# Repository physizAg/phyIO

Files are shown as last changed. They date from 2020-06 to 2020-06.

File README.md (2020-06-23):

# What is PhyIO

PhyIO is an IoT development board with ARM cortex-M4 MCU and CC3100 WiFi chipset. It is designed for tinkerers who need high processing and good wireless connectivity for their IoT projects.

Multiple onboard interfaces like I2C, UART, SPI, and RS485 make it easy to experiment with various sensors and actuators. With its extensive features and rugged design, there are endless possibilities.

# Features

1) Onboard Cortex-M4 based STM32 MCU
2) The PhyIO's wireless chip supports 802.11ac/a/b/g/n WiFI
3) Regulates 12V input to 5V and 3.3V
4) Supports transistor-based switching for driving loads
5) Supports I2C, SPI, UART, and RS485 interface
6) Onboard power indicator LED
7) Flexibility to select specific voltage levels amongst multiple voltage levels for interfaces

## Specs

<li>12V input supply</li>
<li>1 MB Flash memory</li>
<li>256Kb RAM</li>
<li>8 I2C ports</li>
<li>4 SPI ports</li>
<li>1 UART port</li>
<li>RS485 port</li>
<li>10 GPIO ports</li>
<li>4 12-bit ADC channels</li>

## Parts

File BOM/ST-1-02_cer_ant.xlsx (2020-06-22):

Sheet: Лист1
Schematic Reference | Qty | Manufacturer | MPN | Description | SKU
 |  |  |  |  | Digi-Key
ANT1 | 1 | Taiyo Yuden | AH316M245001-T | SMD antenna | 587-2200-1-ND
C1, C2 | 2 | Yageo | CC1206ZKY5V8BB106 | 10uF 25V 1206 smd capacitor | 311-3463-1-ND
C3, C4 | 2 | Yageo | CC0603KRX7R9BB103 | 10nF 50V 0603 X7R, smd capacitor | 311-1085-1-ND
C5, C6 | 2 | Murata | GRM31CR60J107ME39K | 100uF 6.3V 1206 smd capacitor | 490-7217-1-ND
C7, C13, C14, C15, C16, C17, C19, C23 | 8 | Yageo | CC0603KRX7R7BB104 | 0.1uF 16V 0603 smd capacitor | 311-1088-1-ND
C8, C10 | 2 | Yageo | CC0603JRNPO9BN120 | 12pF 0603 smd capacitor | 311-1059-1-ND
C9, C11 | 2 | Yageo | CC0603JRNPO9BN180 | 18pF 0603 smd capacitor | 311-1061-1-ND
C12 | 1 | Yageo | CC0603KRX5R7BB225 | 2.2uF 16V 0603 smd capacitor | 311-1784-1-ND
C20 | 1 | Yageo | CC0402BRNPO9BN1R0 | 1 pF, 0402 ceramic capacitor | 311-3613-1-ND
C21 | 1 | KEMET | T491B107K006AT | B case 100uF, 6V | 399-8301-1-ND
C24, C25 | 2 | Vishay | 293D107X9010D2TE3 | D case 100uF 10V | 718-1056-1-ND
D1, D2 | 2 | STMicroelectronics | STPS140Z | 1.5A Bridge Rectifier | 497-7546-1-ND
D3, D4, D5 | 3 | WГјrth Elektronik | 150060VS75000 | SMD LED, Green | 732-4980-1-ND
D6, D7 | 2 | ON Semiconductor | RB521S30T1G | shottky diode SOD-523 | RB521S30T1GOSCT-ND
L1, L2 | 2 | Bourns | SRN8040-330M | SMD Inductor 33uH | SRN8040-330MCT-ND
L3, L5, L6 | 3 | Murata | BLM18PG121SN1D | Ferrite: bead 120О© 2A 0603 50mО© | 490-1037-1-ND
L4 | 1 | Taiyo Yuden | HK10053N6S-T | 3.6 nH, 0402 inductor | 587-1508-1-ND
Q1, Q2, Q3, Q4, Q5, Q6, Q7, Q8, Q9, Q10 | 10 | Infineon | IRLML2803TRPBF | MOSFET | IRLML2803PBFCT-ND
R1, R2 | 2 | Yageo | RC0603FR-07470KL | 470K 1%, smd resistor | 311-470KHRCT-ND
R3, R5, R16, R19,R20,R25,R26 | 7 | Yageo | RC0603FR-0710KL | 10K, 1%, smd resistor | 311-10.0KHRCT-ND
R4 | 1 | Yageo | RC0603FR-073K24L | 3.24K 1%, smd resistor | 311-3.24KHRCT-ND
R6 | 1 | Yageo | RC0603FR-075K9L | 5.9K 1%, smd resistor | 311-5.90KHRCT-ND
R7 | 1 | Yageo | RC0805FR-07150RL | 150 Ohm 1%, smd resistor | 311-150CRCT-ND
R8, R9 | 2 | Yageo | RC0603FR-07330RL | 330 Ohm 1%, smd resistor | 311-330HRCT-ND
R10, R11, R12, R13, R14 | 5 | Yageo | RC0603FR-071KL | 1K 1%, smd resistor | 311-1.00KHRCT-ND
R15, R17, R18, R21, R22, R23, R24, R27, R28, R29, R30, R33 | 12 | Yageo | RC0603JR-10100KL | 100K, smd resistor | YAG2294CT-ND
R31 | 1 | Yageo | RC0402FR-070RL | 0 Ohm 1%, smd resistor | 311-0.0LRCT-ND
R34 | 1 | Yageo | RC1206JR-07270RL | 270 Ohm, 1206 resistor | 311-270ERCT-ND
R35 | 1 | Yageo | RC1206JR-07180RL | 180 Ohm, 1206 resistor | 311-180ERCT-ND
SW1 | 1 | TE Connectivity | FSMSM | TE smd button switch | 450-1140-ND
U1, U2 | 2 | Texas Instruments | TPS5410DR | Step-down regulator | 296-26982-1-ND
U3 | 1 | STMicroelectronics | ST3485EBDR | MAXIM, RS-422/RS-485 isolated driver | 497-2080-1-ND
U4 | 1 | STMicroelectronics | STM32F412RGT6 | STM32 MCU | 497-16764-ND
U5 | 1 | Texas Instruments | CC3100MODR11MAMOBR | CC3100 MODULE | 296-43589-1-ND
X1, X41 | 2 | WГјrth Elektronik | 691137710002 | 5mm Terminal Block 2pos | 732-10955-ND
X2 | 1 | WГјrth Elektronik | 691137710003 | 5mm Terminal Block 3pos | 732-10956-ND
X3 | 1 | CNC Tech | 3220-10-0300-00 | SWD connector | 1175-1629-ND
X4 | 1 | WГјrth Elektronik | 61300211121 | Male 2 Pos Header Connector 0.1" | 732-5315-ND
X5, X19, X40 | 3 | WГјrth Elektronik | 61300621121 | Male 2x3 Pos Header Connector 0.1" | 732-5295-ND
X6, X7, X8, X9 | 4 | WГјrth Elektronik | 61301421121 | Male 2x7 Pos Header Connector 0.1" | 732-5298-ND
X10 | 1 | WГјrth Elektronik | 61300511121 | Male 5 Pos Header Connector 0.1" | 732-5318-ND
X11, X15, X20, X24, X26, X30, X32, X36, X38, X42, X44, X48, X50, X53 | 14 | WГјrth Elektronik | 61300311121 | Male 3 Pos Header Connector 0.1" | 732-5316-ND
X12, X21, X27, X33, X37, X43, X49, X54 | 8 | Molex | 22-23-2041 | Molex Male 4 Pos Header Connector 0.1" | WM4202-ND
X13, X14, X17, X18, X22, X23, X28, X29, X34, X35 | 10 | Molex | 22-23-2021 | Molex Male 2 Pos Header Connector 0.1" | WM4200-ND
X16, X25, X31, X39, X45 | 5 | Molex | 22-23-2061 | Molex Male 6 Pos Header Connector 0.1" | WM4204-ND
X46, X47 | 2 | WГјrth Elektronik | 61300821121 | Male 2x4 Pos Header Connector 0.1" | 732-5296-ND
X51 | 1 | WГјrth Elektronik | 61300611121 | Male 6 Pos Header Connector 0.1" | 732-5319-ND
X52 | 1 | WГјrth Elektronik | 61301011121 | Male 10 Pos Header Connector 0.1" | 732-2670-ND
X56 | 1 | Harwin | S8411-45R | Battery holder CR1220 | 952-1745-1-ND
Y1 | 1 | ECS International | ECS-.327-12.5-34B-TR | 32.768Khz, Fox, smd quartz crystal | XC1617CT-ND
Y2 | 1 | Abracon | ABM3B-8.000MHZ-B2-T | Crystal 8MHZ SMD5032 | 535-9720-1-ND

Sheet: Лист2
Qty
1
2
2
2
8
2
2
1
1
1
2
2
3
2
2
3
1
10
2
7
1
1
1
2
5
12
1
1
1
1
2
1
1
1
2
1
1
1
3
4
1
14
8
10
5
2
1
1
1
1
1

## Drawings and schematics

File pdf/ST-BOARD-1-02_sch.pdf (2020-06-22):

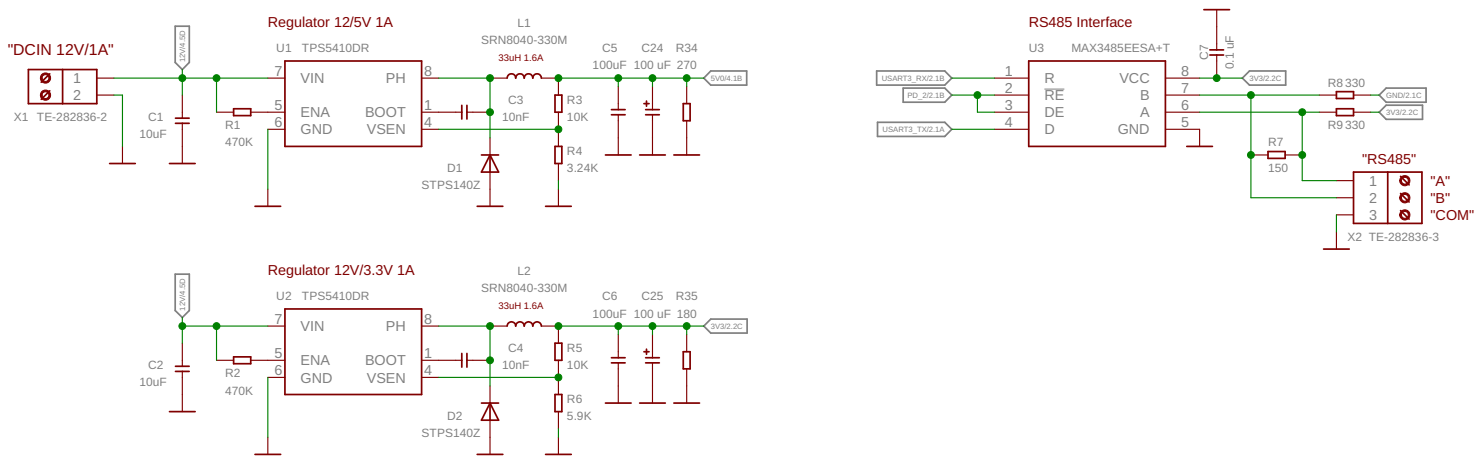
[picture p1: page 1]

Power and RS485

Sheet: 1/4

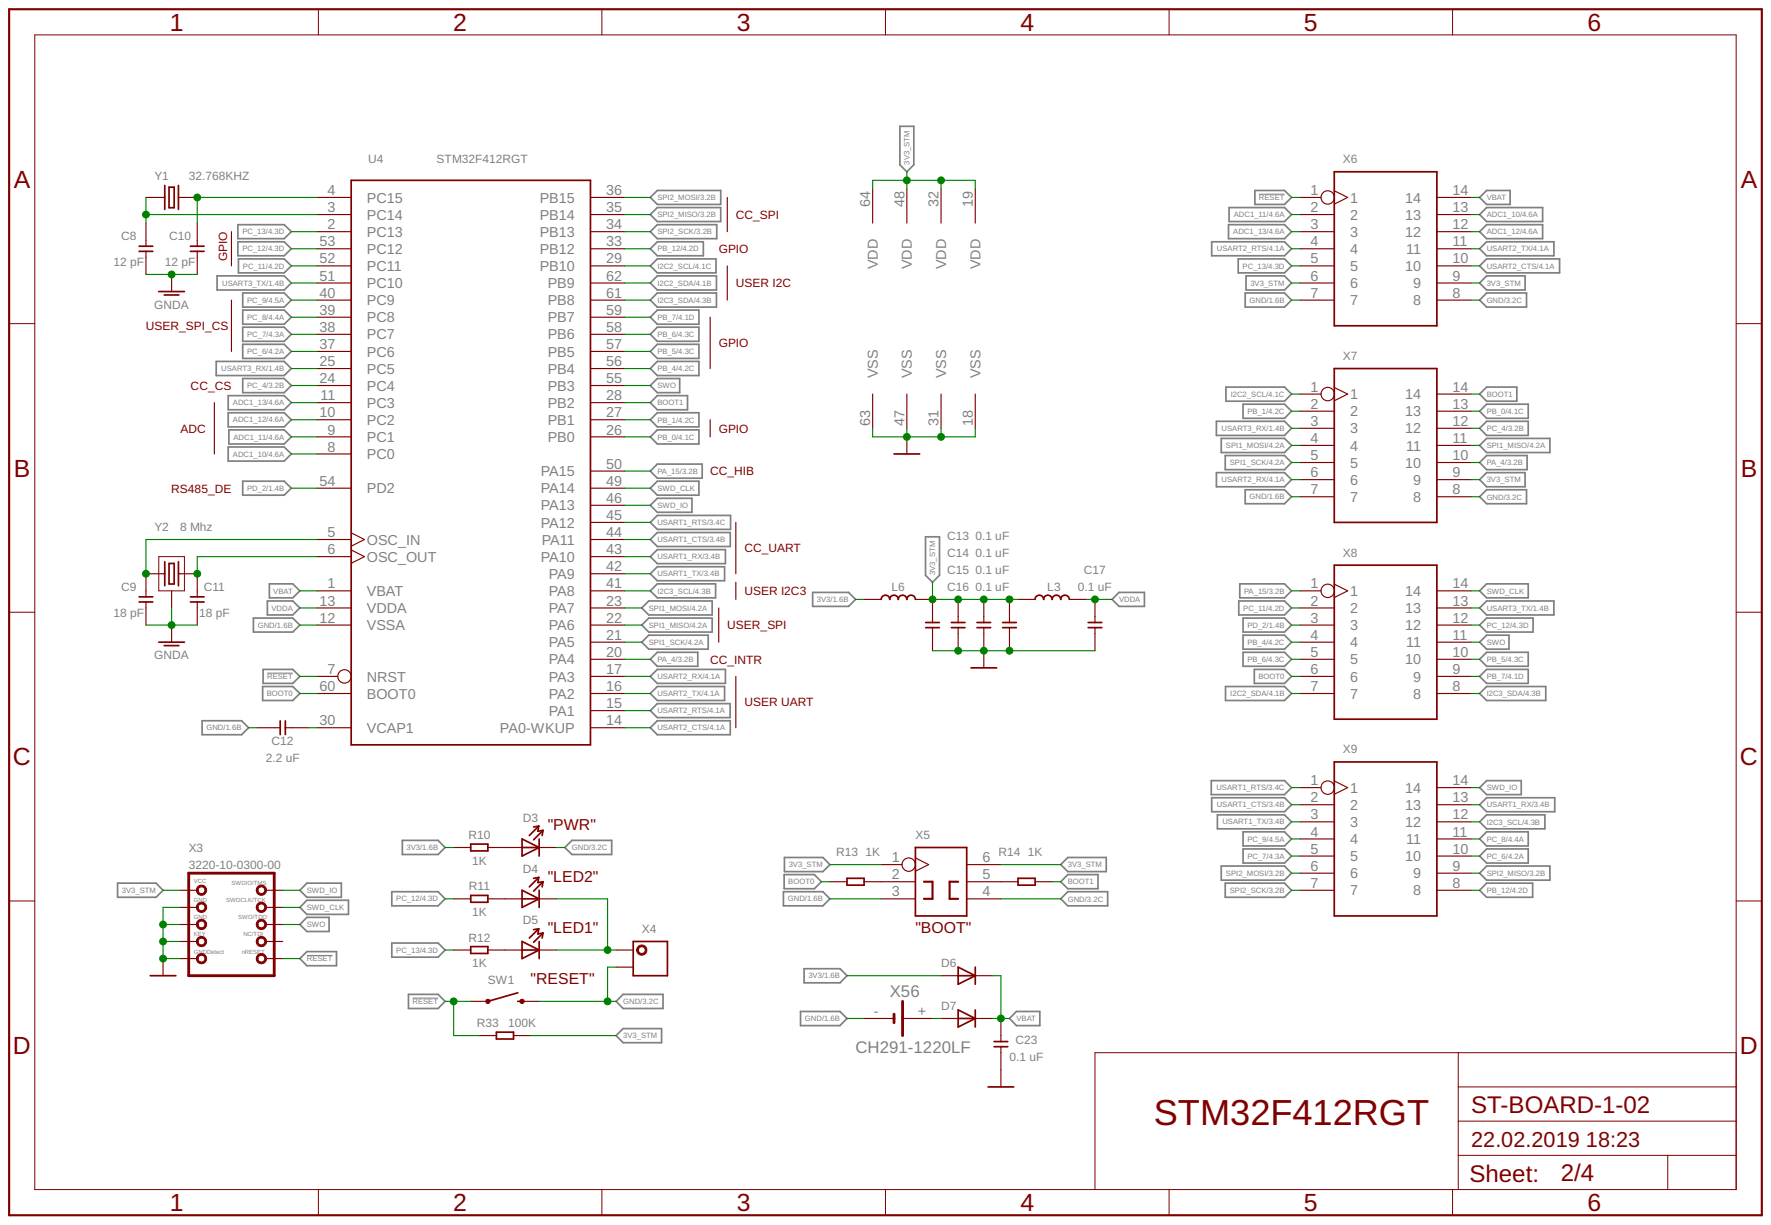
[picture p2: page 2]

nRESET NC/TDI SWO/TDO

STM32F412RGT

Sheet: 2/4

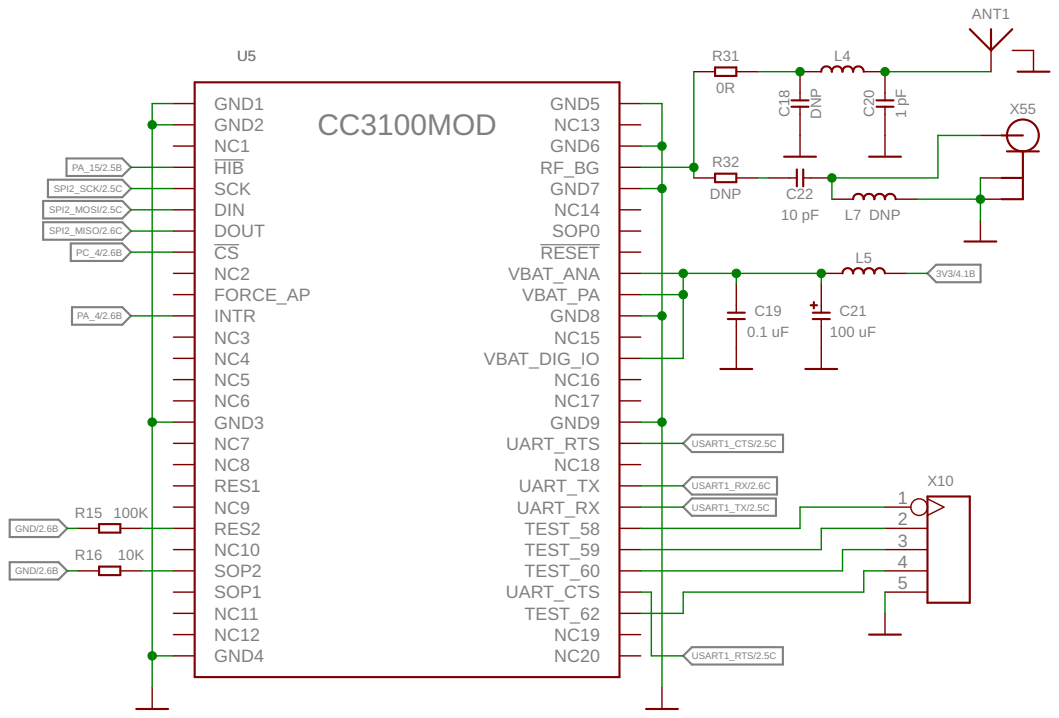
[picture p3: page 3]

Sheet: 3/4

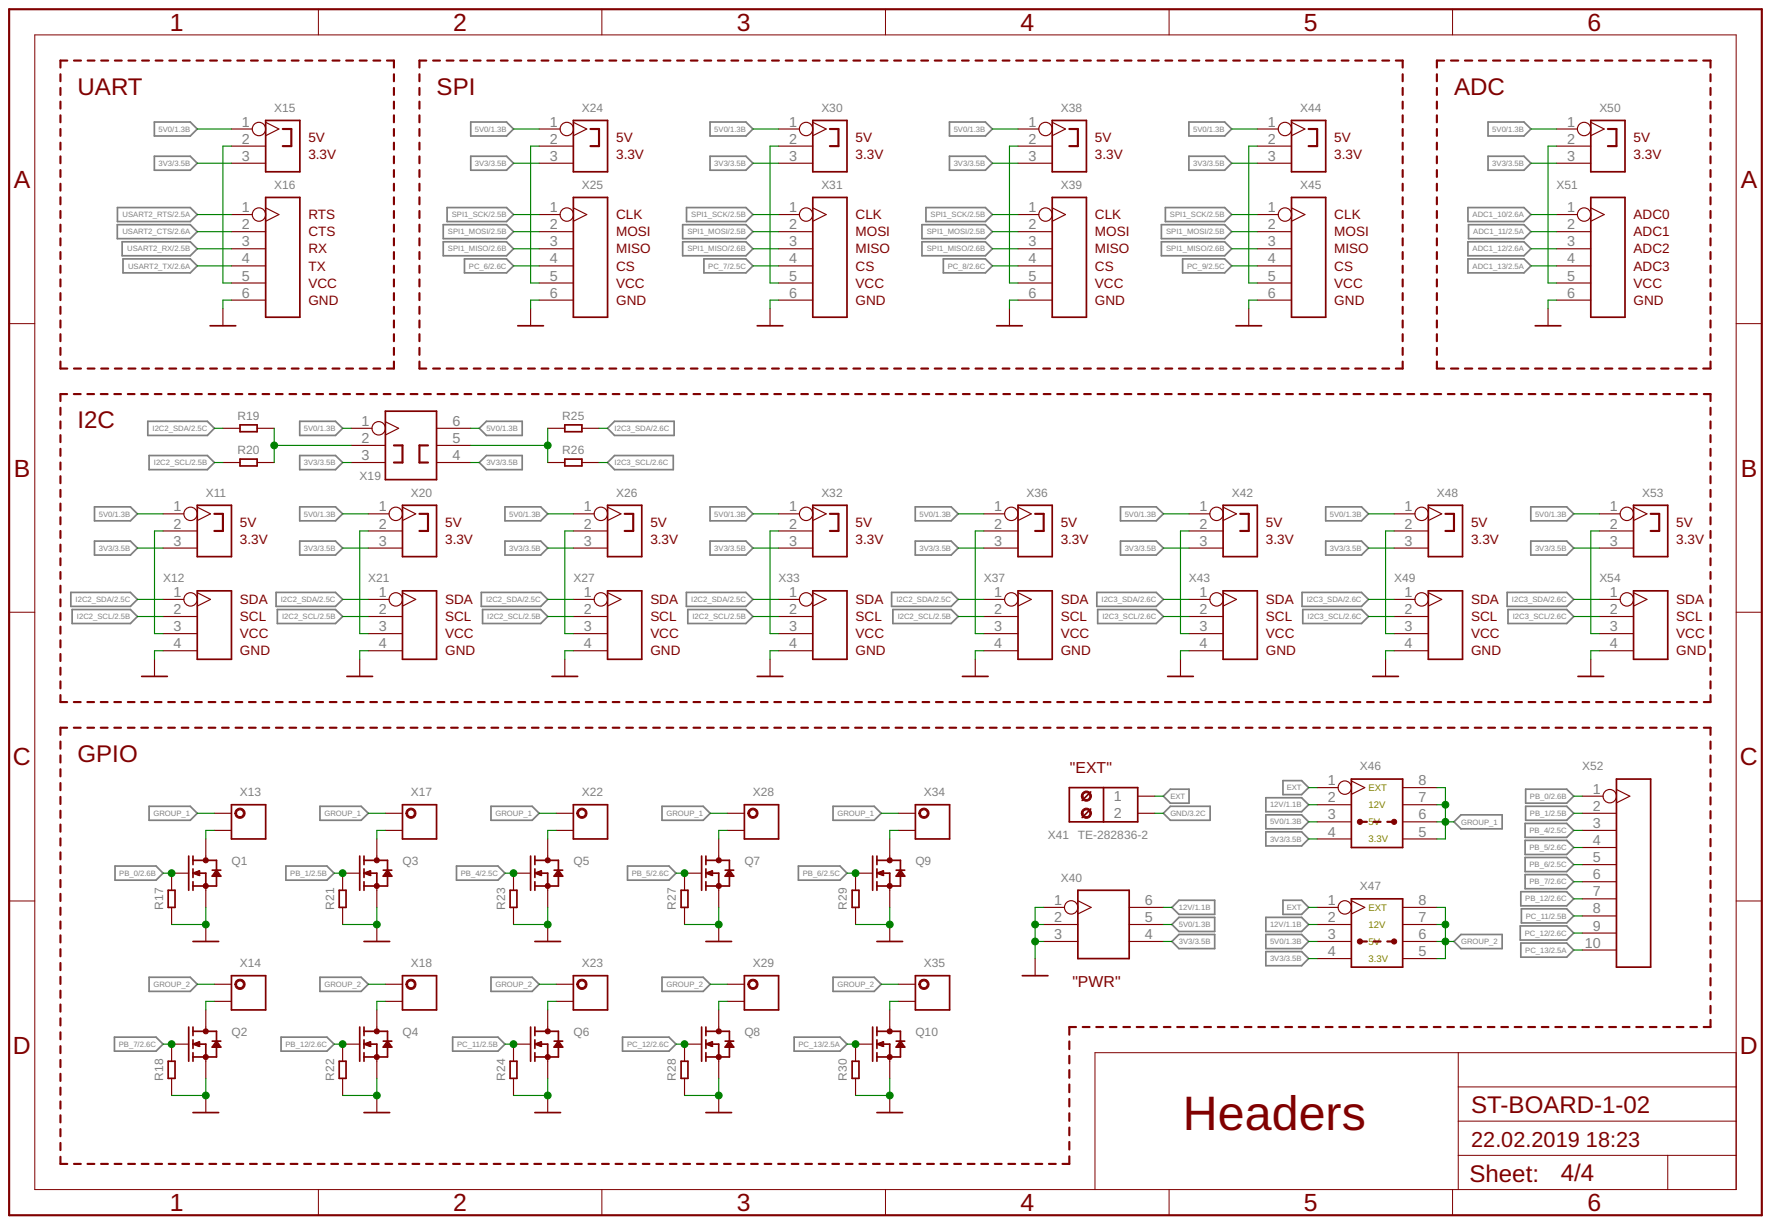
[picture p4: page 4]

Headers

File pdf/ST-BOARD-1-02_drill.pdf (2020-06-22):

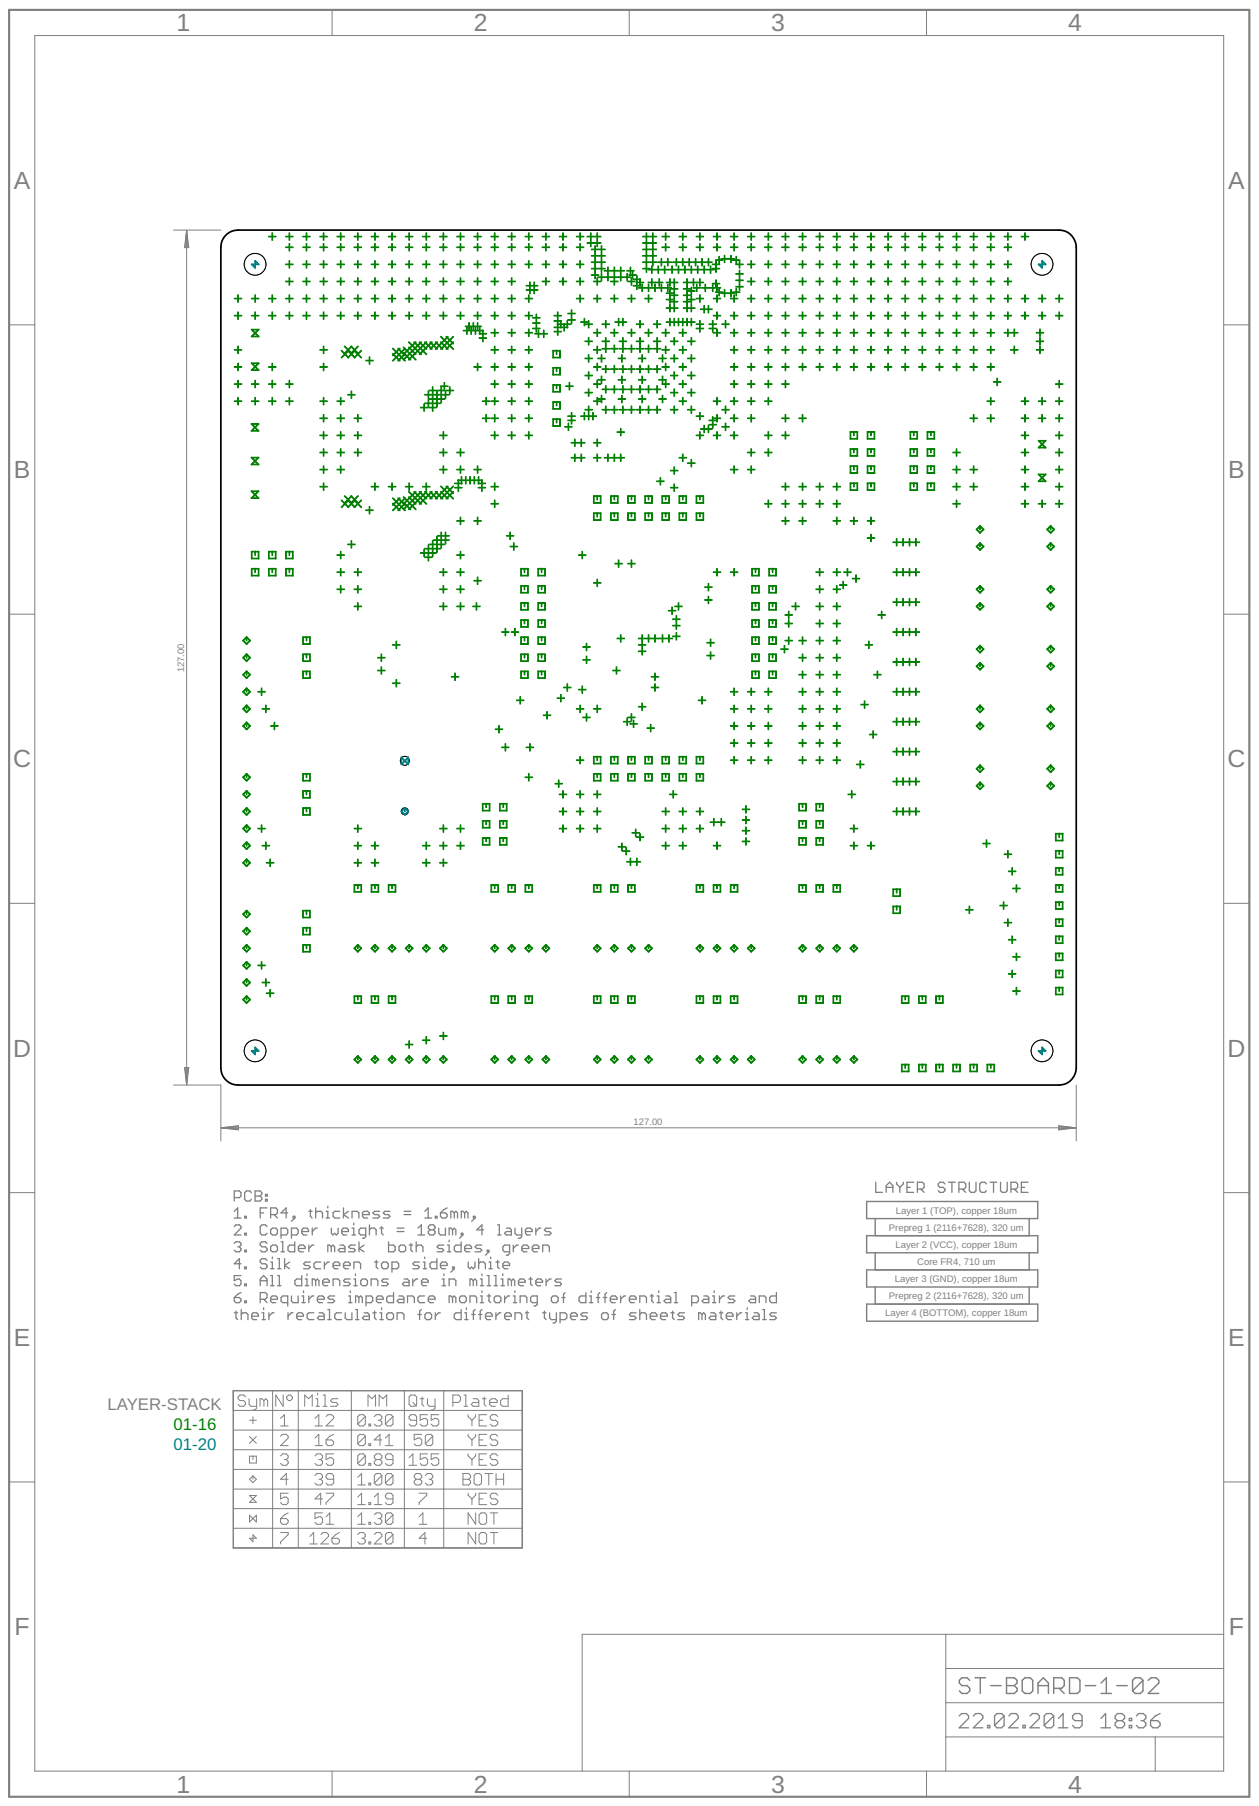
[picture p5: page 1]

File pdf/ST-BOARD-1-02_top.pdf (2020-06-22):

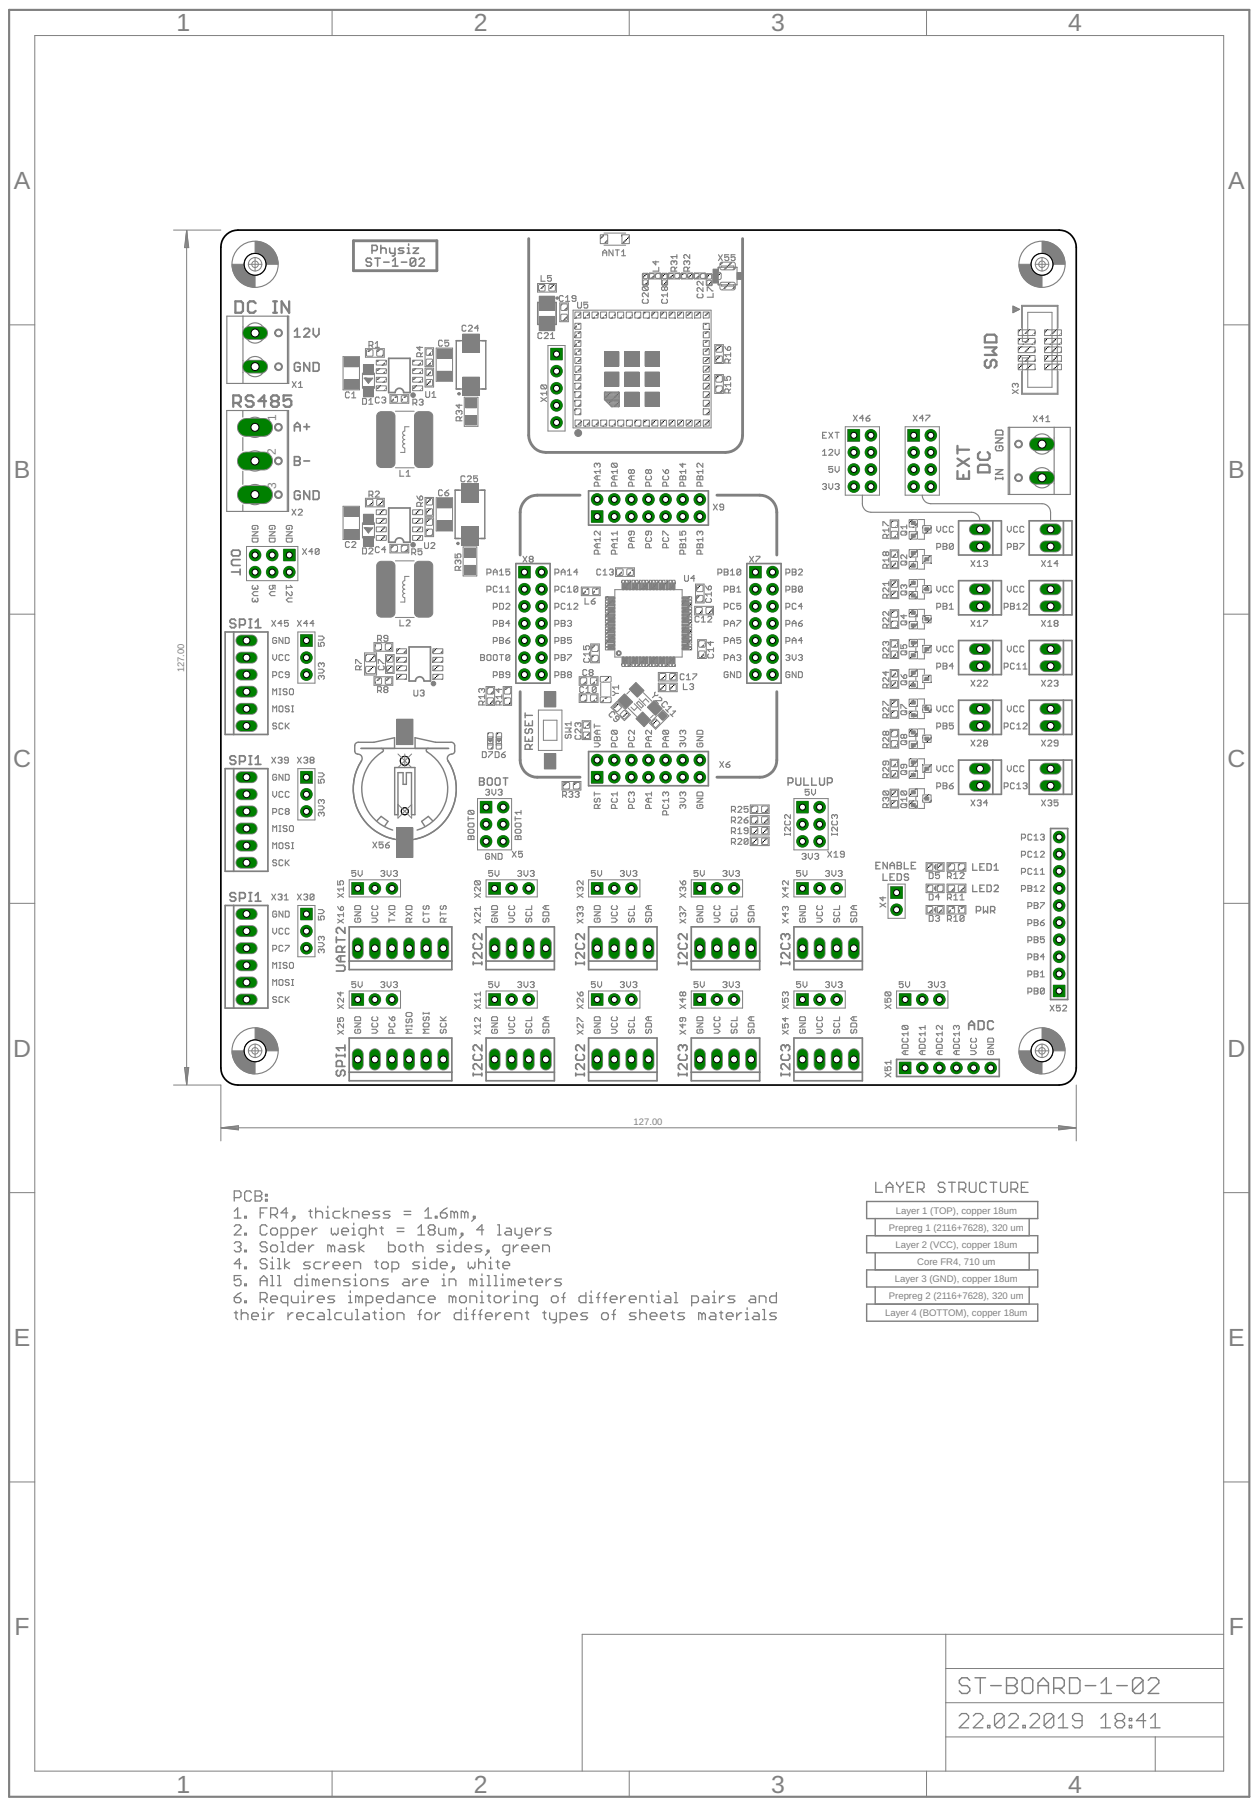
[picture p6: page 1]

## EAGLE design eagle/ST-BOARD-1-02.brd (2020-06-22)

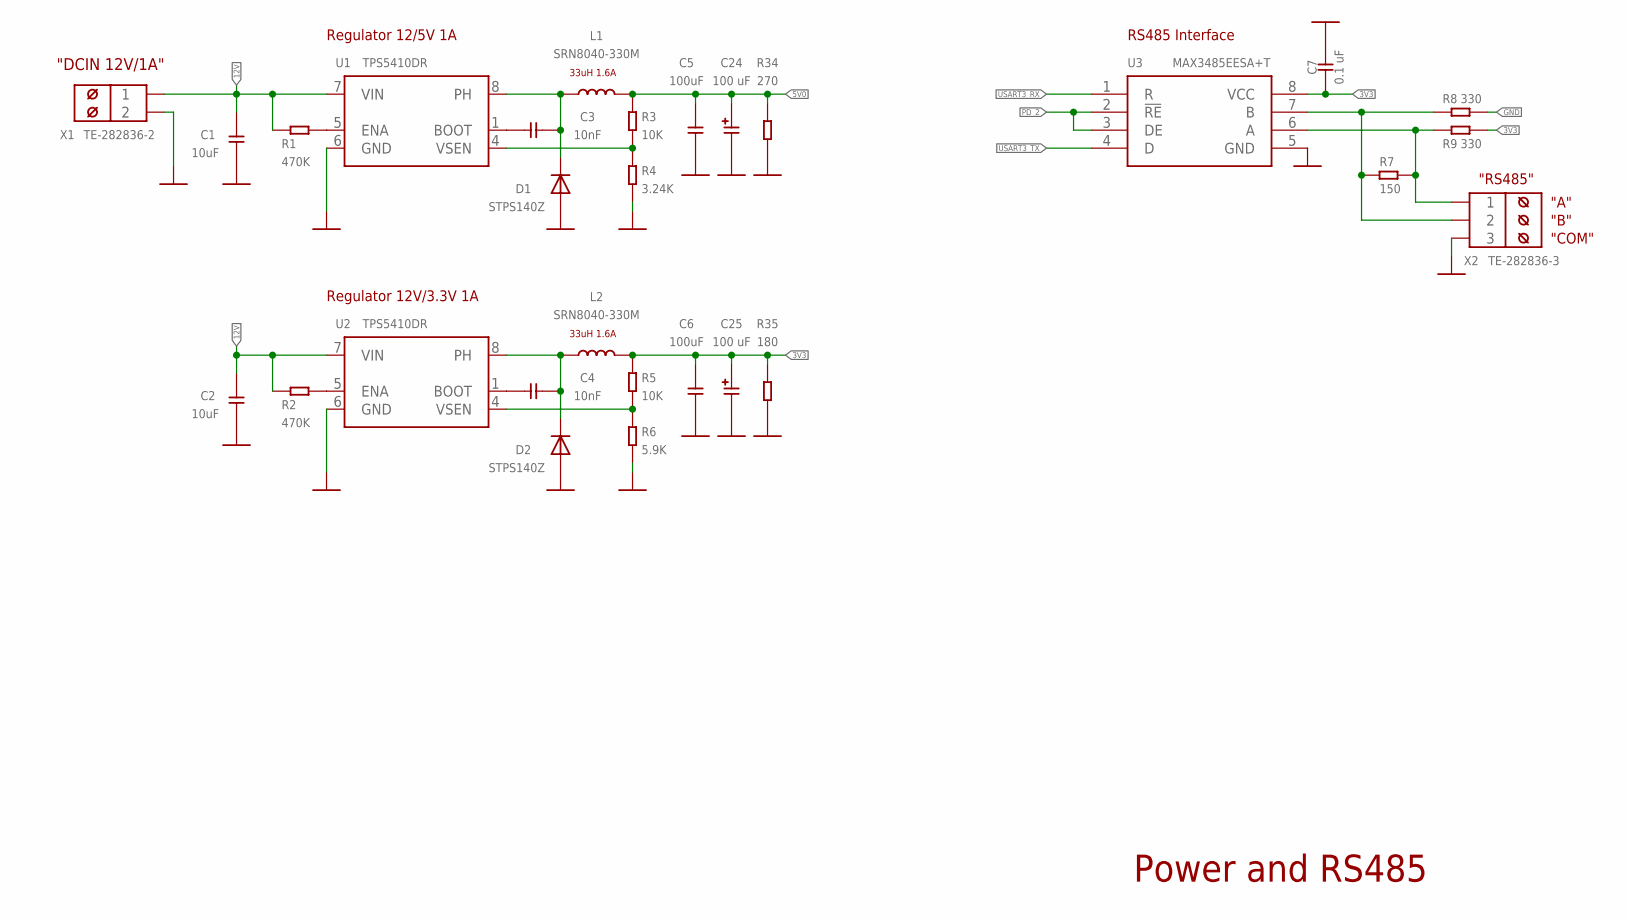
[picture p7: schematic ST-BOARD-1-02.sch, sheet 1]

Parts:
C1, C2: 10uF; C1206
C3, C4: 10nF; C0603
C5, C6: 100uF; C1206
C7: 0.1 uF; C0603
C24, C25: 100 uF; CT7343
D1, D2: STPS140Z; SOD-123
L1, L2: SRN8040-330M; SRN8040
R1, R2: 470K; R0603
R3, R5: 10K; R0603
R4: 3.24K; R0603
R6: 5.9K; R0603
R7: 150; R0805
R8, R9: 330; R0603
R34: 270; R1206
R35: 180; R1206
U1, U2: TPS5410DR; SOIC8
U3: MAX3485EESA+T; SOIC8
X1: TE-282836-2; W237-102
X2: TE-282836-3; W237-103

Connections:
3V3: C6.2, C7.1, C25.+, L2.2, R5.2, R9.1, R35.2, U3.8 (VCC); also elsewhere on the board
5V0: C5.2, C24.+, L1.2, R3.2, R34.2; also elsewhere on the board
12V: C1.1, C2.1, R1.2, R2.2, U1.7 (VIN), U2.7 (VIN), X1.1; also elsewhere on the board
A: R7.2, R9.2, U3.6 (A), X2.1
B: R7.1, R8.2, U3.7 (B), X2.2
GND: C1.2, C2.2, C5.1, C6.1, C7.2, C24.-, C25.-, D1.+, D2.+, R4.1, R6.1, R8.1, R34.1, R35.1, U1.6 (GND), U2.6 (GND), U3.5 (GND), X1.2, X2.3; also elsewhere on the board
LM_SW1: C3.2, D1.-, L1.1, U1.8 (PH)
LM_SW3: C4.2, D2.-, L2.1, U2.8 (PH)
unnamed: R3.1, R4.2, U1.4 (VSEN)
unnamed: C3.1, U1.1 (BOOT)
unnamed: R1.1, U1.5 (ENA)
unnamed: R5.1, R6.2, U2.4 (VSEN)
unnamed: C4.1, U2.1 (BOOT)
unnamed: R2.1, U2.5 (ENA)
PD_2: U3.2 (!RE), U3.3 (DE); also elsewhere on the board
USART3_RX: U3.1 (R); also elsewhere on the board
USART3_TX: U3.4 (D); also elsewhere on the board

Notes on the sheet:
"DCIN 12V/1A"
Regulator 12/5V 1A
33uH 1.6A
Regulator 12V/3.3V 1A
RS485 Interface
"RS485"
"A"
"B"
"COM"
Power and RS485

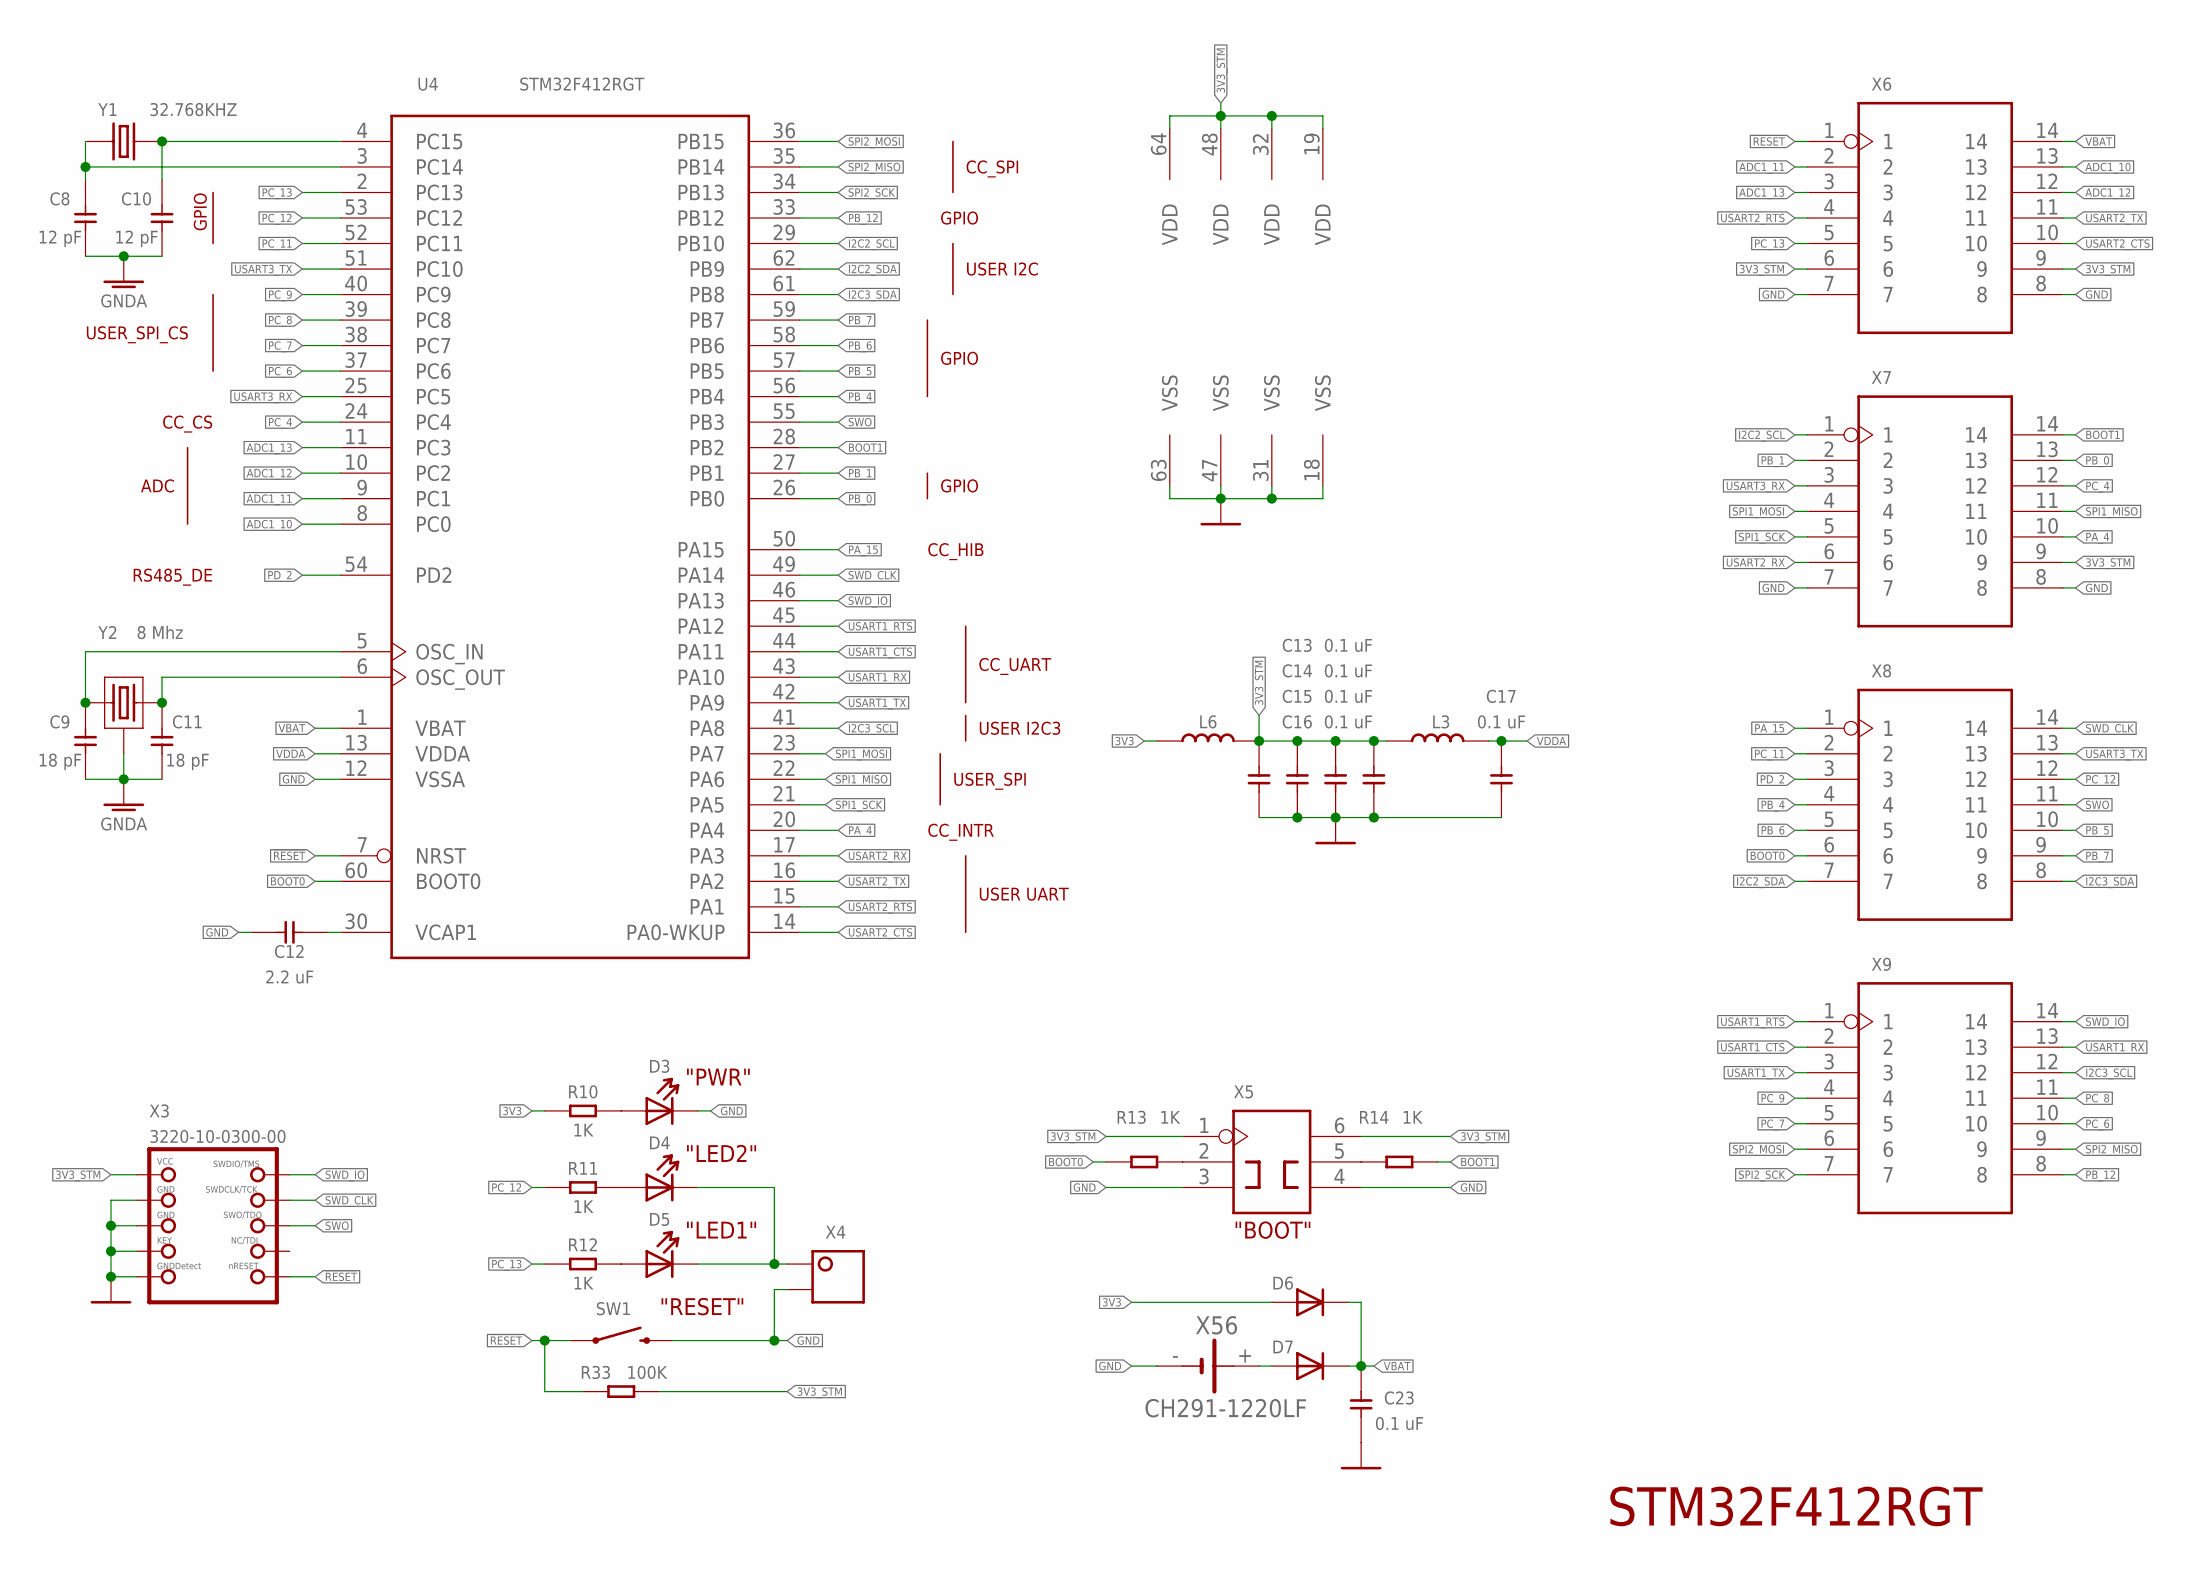
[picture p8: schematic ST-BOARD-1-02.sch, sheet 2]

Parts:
C8, C10: 12 pF; C0603
C9, C11: 18 pF; C0603
C12: 2.2 uF; C0603
C13, C14, C15, C16, C17, C23: 0.1 uF; C0603
D3, D4, D5: LED-0603
D6, D7: DIODE_SOD-523; SOD-523
L3, L6: CHIP-INDUCTOR_L0603; L0603
R10, R11, R12, R13, R14: 1K; R0603
R33: 100K; R0603
SW1: TE-1437566-3
U4: STM32F412RGT; LQFP64
X3: 3220-10-0300-00; 2X05_1.27MM_BOX_NOPOSTS
X4: 2p-2.54; H2-2.54
X5: 2x3p-2.54; H2X3-2.54
X6, X7, X8, X9: DIP-HEADER-VERT(2X7P-2.54); H2X7-2.54
X56: CH291-1220LF
Y1: 32.768KHZ; 3.2X1.5; MPN KX-327NHT 32.768 kHz GEYER
Y2: 8 Mhz; IQG5032B

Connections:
3V3: D6.+, L6.1, R10.1; also elsewhere on the board
3V3_STM: C13.1, C14.1, C15.1, C16.1, L3.2, L6.2, R33.1, U4.19 (VDD), U4.32 (VDD), U4.48 (VDD), U4.64 (VDD), X3.1 (VCC), X5.1, X5.6, X6.6, X6.9, X7.9
!RESET: R33.2, SW1.P$1 (1), U4.7 (NRST), X3.10 (NRESET), X6.1
ADC1_10: U4.8 (PC0), X6.13; also elsewhere on the board
ADC1_11: U4.9 (PC1), X6.2; also elsewhere on the board
ADC1_12: U4.10 (PC2), X6.12; also elsewhere on the board
ADC1_13: U4.11 (PC3), X6.3; also elsewhere on the board
BOOT0: R13.1, U4.60 (BOOT0), X8.6
BOOT1: R14.1, U4.28 (PB2), X7.14
GND: C12.2, C13.2, C14.2, C15.2, C16.2, C17.2, C23.2, D3.-, SW1.P$2 (2), U4.12 (VSSA), U4.18 (VSS), U4.31 (VSS), U4.47 (VSS), U4.63 (VSS), X3.3 (GND), X3.5 (GND), X3.7 (KEY), X3.9 (GNDDETECT), X4.2, X5.3, X5.4, X6.7, X6.8, X7.7, X7.8, X56.-; also elsewhere on the board
GNDA: C8.1, C9.1, C10.1, C11.1, Y2.2 (GND), Y2.4 (GND)
I2C2_SCL: U4.29 (PB10), X7.1; also elsewhere on the board
I2C2_SDA: U4.62 (PB9), X8.7; also elsewhere on the board
I2C3_SCL: U4.41 (PA8), X9.12; also elsewhere on the board
I2C3_SDA: U4.61 (PB8), X8.8; also elsewhere on the board
unnamed: C10.2, U4.4 (PC15), Y1.2
unnamed: C8.2, U4.3 (PC14), Y1.1
unnamed: C12.1, U4.30 (VCAP1)
unnamed: C11.2, U4.6 (OSC_OUT), Y2.3 (2)
unnamed: C9.2, U4.5 (OSC_IN), Y2.1
unnamed: D3.+, R10.2
unnamed: D4.+, R11.2
unnamed: D5.+, R12.2
unnamed: D7.+, X56.+
unnamed: R14.2, X5.5
unnamed: R13.2, X5.2
unnamed: D4.-, D5.-, X4.1
PA_4: U4.20 (PA4), X7.10; also elsewhere on the board
PA_15: U4.50 (PA15), X8.1; also elsewhere on the board
PB_0: U4.26 (PB0), X7.13; also elsewhere on the board
PB_1: U4.27 (PB1), X7.2; also elsewhere on the board
PB_4: U4.56 (PB4), X8.4; also elsewhere on the board
PB_5: U4.57 (PB5), X8.10; also elsewhere on the board
PB_6: U4.58 (PB6), X8.5; also elsewhere on the board
PB_7: U4.59 (PB7), X8.9; also elsewhere on the board
PB_12: U4.33 (PB12), X9.8; also elsewhere on the board
PC_4: U4.24 (PC4), X7.12; also elsewhere on the board
PC_6: U4.37 (PC6), X9.10; also elsewhere on the board
PC_7: U4.38 (PC7), X9.5; also elsewhere on the board
PC_8: U4.39 (PC8), X9.11; also elsewhere on the board
PC_9: U4.40 (PC9), X9.4; also elsewhere on the board
PC_11: U4.52 (PC11), X8.2; also elsewhere on the board
PC_12: R11.1, U4.53 (PC12), X8.12; also elsewhere on the board
PC_13: R12.1, U4.2 (PC13), X6.5; also elsewhere on the board
PD_2: U4.54 (PD2), X8.3; also elsewhere on the board
SPI1_MISO: U4.22 (PA6), X7.11; also elsewhere on the board
SPI1_MOSI: U4.23 (PA7), X7.4; also elsewhere on the board
SPI1_SCK: U4.21 (PA5), X7.5; also elsewhere on the board
SPI2_MISO: U4.35 (PB14), X9.9; also elsewhere on the board
SPI2_MOSI: U4.36 (PB15), X9.6; also elsewhere on the board
SPI2_SCK: U4.34 (PB13), X9.7; also elsewhere on the board
SWD_CLK: U4.49 (PA14), X3.4 (SWDCLK), X8.14
SWD_IO: U4.46 (PA13), X3.2 (SWDIO), X9.14
SWO: U4.55 (PB3), X3.6 (SWO), X8.11
USART1_CTS: U4.44 (PA11), X9.2; also elsewhere on the board
USART1_RTS: U4.45 (PA12), X9.1; also elsewhere on the board
USART1_RX: U4.43 (PA10), X9.13; also elsewhere on the board
USART1_TX: U4.42 (PA9), X9.3; also elsewhere on the board
USART2_CTS: U4.14 (PA0-WKUP), X6.10; also elsewhere on the board
USART2_RTS: U4.15 (PA1), X6.4; also elsewhere on the board
USART2_RX: U4.17 (PA3), X7.6; also elsewhere on the board
USART2_TX: U4.16 (PA2), X6.11; also elsewhere on the board
USART3_RX: U4.25 (PC5), X7.3; also elsewhere on the board
USART3_TX: U4.51 (PC10), X8.13; also elsewhere on the board
VBAT: C23.1, D6.-, D7.-, U4.1 (VBAT), X6.14
VDDA: C17.1, L3.1, U4.13 (VDDA)

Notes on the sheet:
STM32F412RGT
"PWR"
"LED2"
"LED1"
"RESET"
USER UART
CC_UART
USER_SPI
USER I2C
USER I2C3
CC_SPI
"BOOT"
RS485_DE
ADC
GPIO
USER_SPI_CS
CC_INTR
CC_HIB
CC_CS

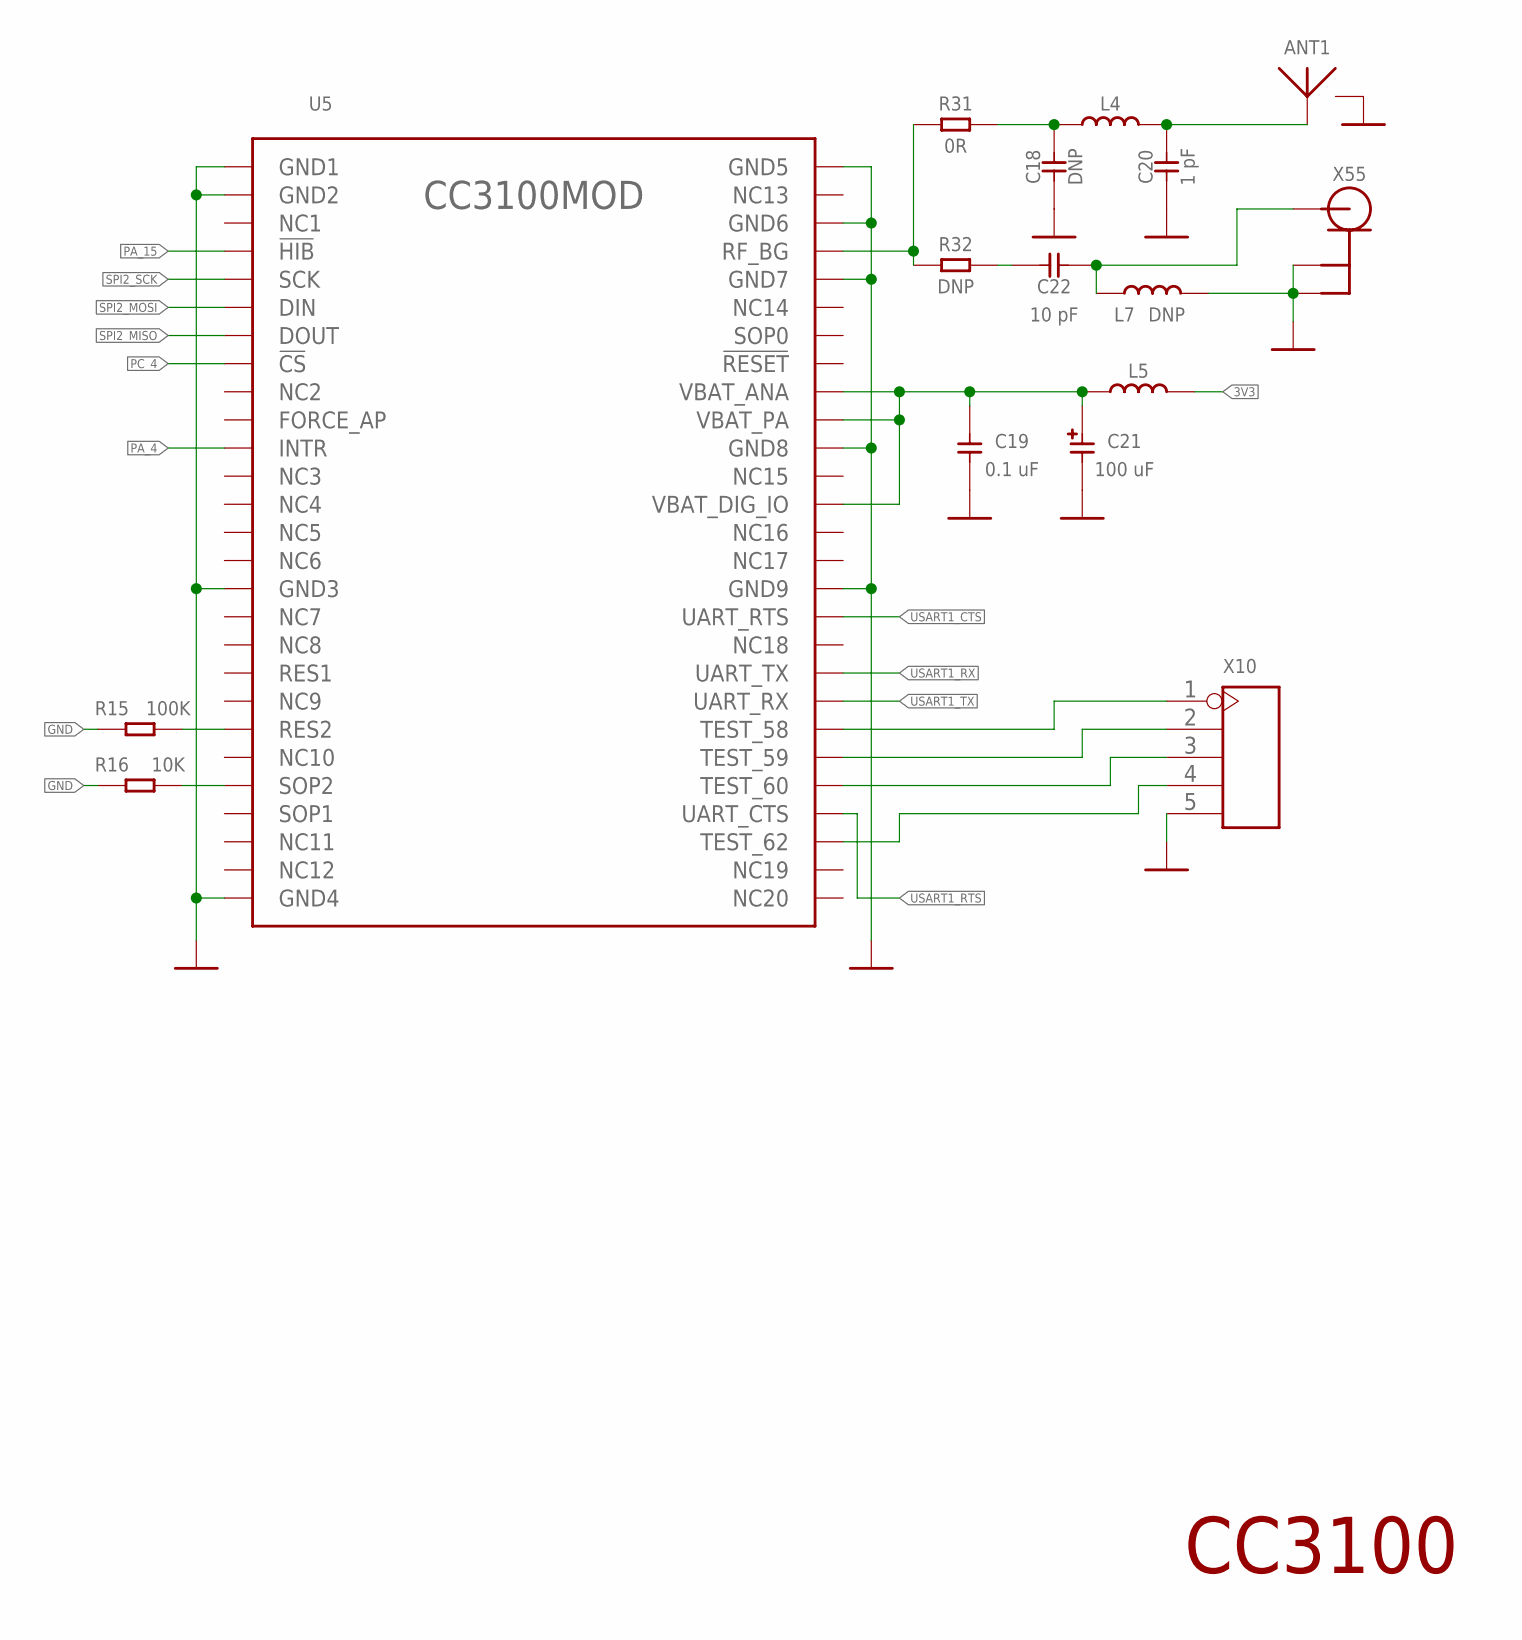
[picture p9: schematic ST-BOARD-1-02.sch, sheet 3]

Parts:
ANT1: AH316M245001-T; AH316M
C18: DNP; C0402
C19: 0.1 uF; C0603
C20: 1 pF; C0402
C21: 100 uF; CT3528
C22: 10 pF; C0402
L4: CHIP-INDUCTOR_L0402; L0402
L5: CHIP-INDUCTOR_L0603; L0603
L7: DNP; L0402
R15: 100K; R0603
R16: 10K; R0603
R31: 0R; R0402
R32: DNP; R0402
U5: CC3100MOD
X10: 2p-2.54; H5-2.54
X55: UFL3; U-FL3P-SMD-2.6X2.6X1.0MM

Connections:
3V3: L5.2; also elsewhere on the board
GND: ANT1.P$2 (GND), C18.1, C19.2, C20.1, C21.-, L7.2, R15.1, R16.1, U5.P1 (GND1), U5.P2 (GND2), U5.P16 (GND3), U5.P27 (GND4), U5.P28 (GND5), U5.P30 (GND6), U5.P32 (GND7), U5.P38 (GND8), U5.P43 (GND9), U5.P55 (GND1), U5.P56 (GND1), U5.P57 (GND1), U5.P58 (GND1), U5.P59 (GND1), U5.P60 (GND1), U5.P61 (GND1), U5.P62 (GND1), U5.P63 (GND1), X10.5, X55.GND1 (GND), X55.GND2 (GND1); also elsewhere on the board
unnamed: R15.2, U5.P21 (RES2)
unnamed: R16.2, U5.P23 (SOP2)
unnamed: R31.1, R32.1, U5.P31 (RF_BG)
unnamed: ANT1.P$1 (ANT), C20.2, L4.2
unnamed: C19.1, C21.+, L5.1, U5.P36 (VBAT_ANA), U5.P37 (VBAT_PA), U5.P40 (VBAT_DIG_IO)
unnamed: C18.2, L4.1, R31.2
unnamed: C22.2, R32.2
unnamed: C22.1, L7.1, X55.D (ANT)
PA_4: U5.P11 (INTR); also elsewhere on the board
PA_15: U5.P4 (!HIB); also elsewhere on the board
PC_4: U5.P8 (!CS); also elsewhere on the board
SPI2_MISO: U5.P7 (DOUT); also elsewhere on the board
SPI2_MOSI: U5.P6 (DIN); also elsewhere on the board
SPI2_SCK: U5.P5 (SCK); also elsewhere on the board
TEST_58: U5.P48 (TEST_58), X10.1
TEST_59: U5.P49 (TEST_59), X10.2
TEST_60: U5.P50 (TEST_60), X10.3
TEST_62: U5.P52 (TEST_62), X10.4
USART1_CTS: U5.P44 (UART_RTS); also elsewhere on the board
USART1_RTS: U5.P51 (UART_CTS); also elsewhere on the board
USART1_RX: U5.P46 (UART_TX); also elsewhere on the board
USART1_TX: U5.P47 (UART_RX); also elsewhere on the board

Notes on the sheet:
CC3100

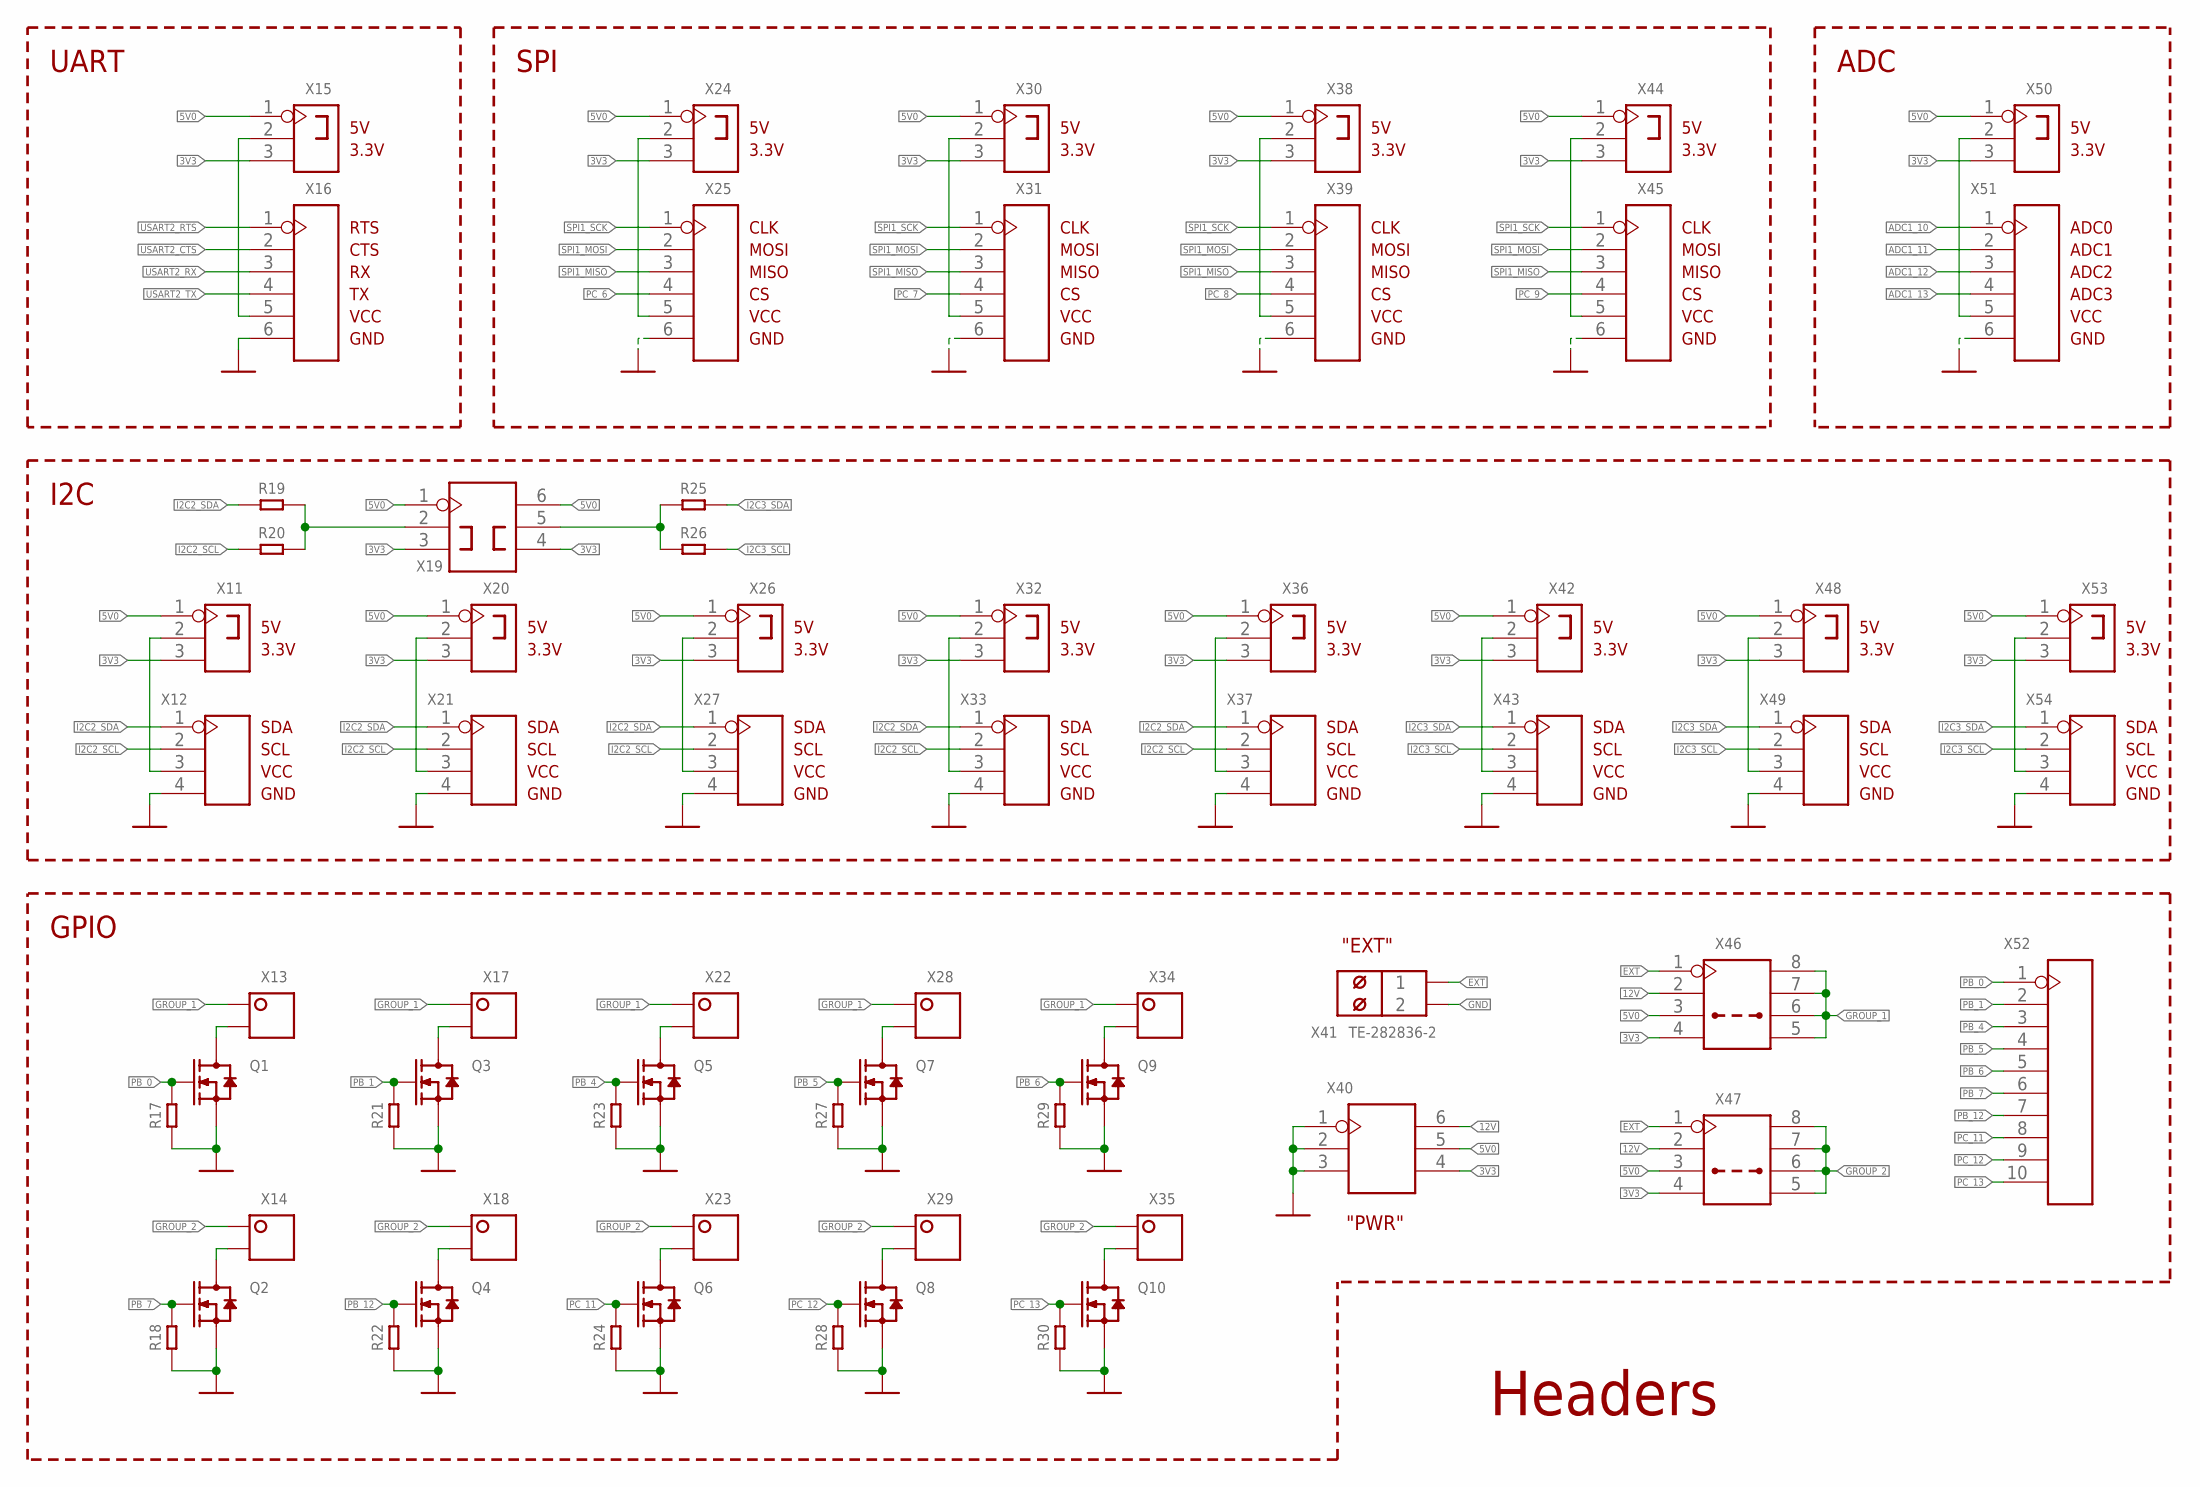
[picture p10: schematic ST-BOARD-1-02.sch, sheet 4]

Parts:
Q1, Q2, Q3, Q4, Q5, Q6, Q7, Q8, Q9, Q10: MOSFET-N-(SOT-23); SOT-23
R17, R18, R19, R20, R21, R22, R23, R24, R25, R26, R27, R28, R29, R30: CHIP-RESISTOR-0603; R0603
X11, X15, X20, X24, X26, X30, X32, X36, X38, X42, X44, X48, X50, X53: 3p-2.54; H3-2.54
X12, X21, X27, X33, X37, X43, X49, X54: DIP-HEADER-VERT(4P-2.54)_WF; 22-23-2041
X13, X14, X17, X18, X22, X23, X28, X29, X34, X35: 2p-2.54; 22-23-2021
X16, X25, X31, X39, X45: DIP-HEADER-VERT(6P-2.54)_WF; 22-23-2061
X19, X40: 2x3p-2.54; H2X3-2.54
X41: TE-282836-2; W237-102
X46, X47: 2x4p-2.54; H2X4-2.54
X51: DIP-HEADER-VERT(6P-2.54); H6-2.54
X52: DIP-HEADER-VERT(10P-2.54); H10-2.54

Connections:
3V3: X11.3, X15.3, X19.3, X19.4, X20.3, X24.3, X26.3, X30.3, X32.3, X36.3, X38.3, X40.4, X42.3, X44.3, X46.4, X47.4, X48.3, X50.3, X53.3; also elsewhere on the board
5V0: X11.1, X15.1, X19.1, X19.6, X20.1, X24.1, X26.1, X30.1, X32.1, X36.1, X38.1, X40.5, X42.1, X44.1, X46.3, X47.3, X48.1, X50.1, X53.1; also elsewhere on the board
12V: X40.6, X46.2, X47.2; also elsewhere on the board
ADC1_10: X51.1; also elsewhere on the board
ADC1_11: X51.2; also elsewhere on the board
ADC1_12: X51.3; also elsewhere on the board
ADC1_13: X51.4; also elsewhere on the board
EXT: X41.1, X46.1, X47.1
GND: Q1.2 (S), Q2.2 (S), Q3.2 (S), Q4.2 (S), Q5.2 (S), Q6.2 (S), Q7.2 (S), Q8.2 (S), Q9.2 (S), Q10.2 (S), R17.1, R18.1, R21.1, R22.1, R23.1, R24.1, R27.1, R28.1, R29.1, R30.1, X12.4, X16.6, X21.4, X25.6, X27.4, X31.6, X33.4, X37.4, X39.6, X40.1, X40.2, X40.3, X41.2, X43.4, X45.6, X49.4, X51.6, X54.4; also elsewhere on the board
GROUP_1: X13.1, X17.1, X22.1, X28.1, X34.1, X46.5, X46.6, X46.7, X46.8
GROUP_2: X14.1, X18.1, X23.1, X29.1, X35.1, X47.5, X47.6, X47.7, X47.8
I2C2_SCL: R20.1, X12.2, X21.2, X27.2, X33.2, X37.2; also elsewhere on the board
I2C2_SDA: R19.1, X12.1, X21.1, X27.1, X33.1, X37.1; also elsewhere on the board
I2C3_SCL: R26.1, X43.2, X49.2, X54.2; also elsewhere on the board
I2C3_SDA: R25.1, X43.1, X49.1, X54.1; also elsewhere on the board
unnamed: R19.2, R20.2, X19.2
unnamed: X11.2, X12.3
unnamed: X20.2, X21.3
unnamed: X15.2, X16.5
unnamed: X26.2, X27.3
unnamed: Q1.3 (D), X13.2
unnamed: Q3.3 (D), X17.2
unnamed: X32.2, X33.3
unnamed: X36.2, X37.3
unnamed: X42.2, X43.3
unnamed: X48.2, X49.3
unnamed: X53.2, X54.3
unnamed: X24.2, X25.5
unnamed: X30.2, X31.5
unnamed: X38.2, X39.5
unnamed: X44.2, X45.5
unnamed: X50.2, X51.5
unnamed: Q5.3 (D), X22.2
unnamed: Q7.3 (D), X28.2
unnamed: Q9.3 (D), X34.2
unnamed: Q2.3 (D), X14.2
unnamed: Q4.3 (D), X18.2
unnamed: Q6.3 (D), X23.2
unnamed: Q8.3 (D), X29.2
unnamed: Q10.3 (D), X35.2
unnamed: R25.2, R26.2, X19.5
PB_0: Q1.1 (G), R17.2, X52.1; also elsewhere on the board
PB_1: Q3.1 (G), R21.2, X52.2; also elsewhere on the board
PB_4: Q5.1 (G), R23.2, X52.3; also elsewhere on the board
PB_5: Q7.1 (G), R27.2, X52.4; also elsewhere on the board
PB_6: Q9.1 (G), R29.2, X52.5; also elsewhere on the board
PB_7: Q2.1 (G), R18.2, X52.6; also elsewhere on the board
PB_12: Q4.1 (G), R22.2, X52.7; also elsewhere on the board
PC_6: X25.4; also elsewhere on the board
PC_7: X31.4; also elsewhere on the board
PC_8: X39.4; also elsewhere on the board
PC_9: X45.4; also elsewhere on the board
PC_11: Q6.1 (G), R24.2, X52.8; also elsewhere on the board
PC_12: Q8.1 (G), R28.2, X52.9; also elsewhere on the board
PC_13: Q10.1 (G), R30.2, X52.10; also elsewhere on the board
SPI1_MISO: X25.3, X31.3, X39.3, X45.3; also elsewhere on the board
SPI1_MOSI: X25.2, X31.2, X39.2, X45.2; also elsewhere on the board
SPI1_SCK: X25.1, X31.1, X39.1, X45.1; also elsewhere on the board
USART2_CTS: X16.2; also elsewhere on the board
USART2_RTS: X16.1; also elsewhere on the board
USART2_RX: X16.3; also elsewhere on the board
USART2_TX: X16.4; also elsewhere on the board

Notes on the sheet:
3.3V
VCC
GND
UART
SDA
SCL
CLK
MOSI
MISO
ADC0
ADC1
ADC2
ADC3
SPI
GPIO
I2C
ADC
Headers
CTS
RTS
"EXT"
"PWR"

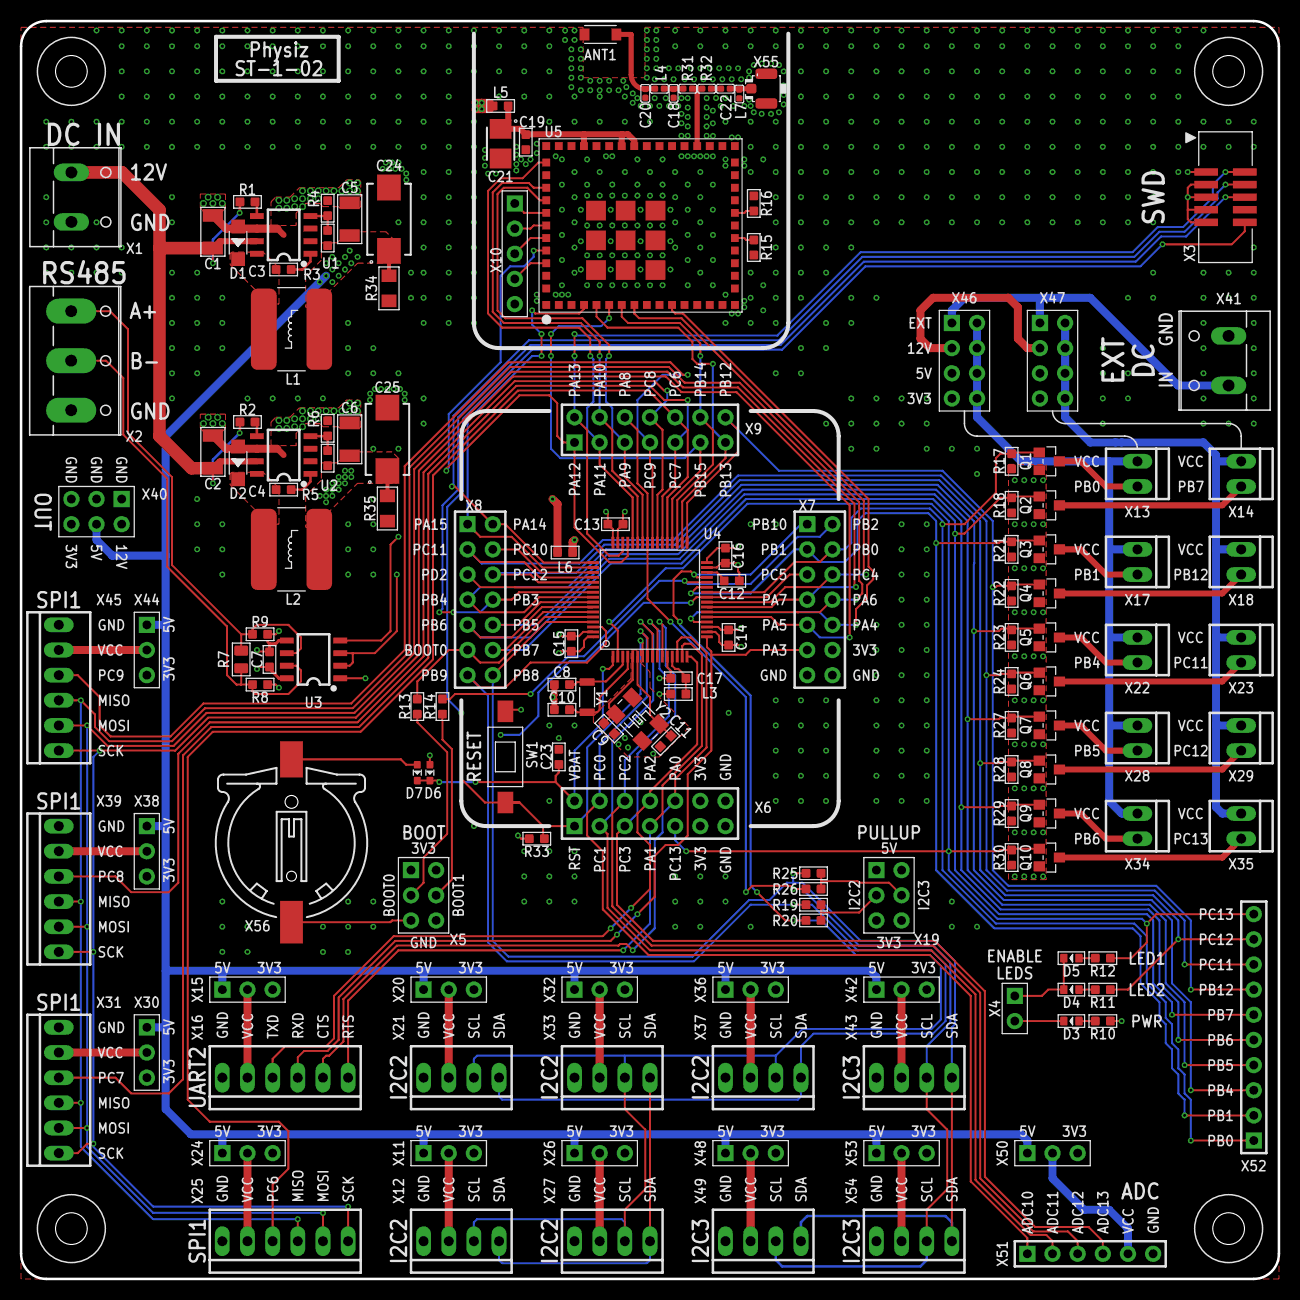
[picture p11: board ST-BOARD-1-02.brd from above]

Board: 4 copper layers, 127.0 x 127.0 mm, 155 parts (0 on the bottom side), 119 nets.

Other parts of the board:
DRILEGEND: DRILEGEND
U$1, U$2, U$3, U$4: 3,2
U$5: A4P-LOC
